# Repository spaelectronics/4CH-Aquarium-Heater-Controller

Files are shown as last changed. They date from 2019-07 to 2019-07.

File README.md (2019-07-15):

# Parts Needed
QTY: 1 - ITEM: C8 Power Socket Panel Mount  
URL: https://www.digikey.com/product-detail/en/qualtek/770W-X2-13/Q840-ND/1466563

QTY: 1 - ITEM: 4.7K Ohm Resistor  
URL: https://www.taydaelectronics.com/10-x-resistor-4-7k-ohm-1-4w-1-metal-film-pkg-of-10.html

QTY: 1 - ITEM: 3300UF 16V ELECTROLYTIC CAPACITOR  
URL: https://www.taydaelectronics.com/capacitors/electrolytic-capacitors/3300uf-16v-105c-radial-electrolytic-capacitor-13x21mm.html

QTY: 4 - ITEM: 3.5mm Stereo Plug  
URL: https://www.taydaelectronics.com/3-5mm-stereo-plug.html

QTY: 4 - ITEM: 3.5mm Stereo Jack  
URL: https://www.taydaelectronics.com/pj-392-3-5mm-stereo-enclosed-chassis-socket.html

QTY: 4 - ITEM: DS18B20 Waterproof Temperature Sensor  
URL: https://www.banggood.com/DS18B20-Waterproof-Digital-Temperature-Temp-Sensor-Probe-1M-2M-3M-5M-10M-15M-p-983801.html

QTY: 4 - ITEM: 2 Prong US Power Socket  
URL: https://www.amazon.com/uxcell-Panel-Mount-Outlet-Socket/dp/B01GKMPXTO/

QTY: 1 - ITEM: Passive Piezo Buzzer  
URL: https://www.banggood.com/DC-1-30V-2-Pins-Passive-Electronic-Piezoelectric-Piezo-Buzzer-p-978657.html

QTY: 1 - ITEM: AC-DC 5V 1A Step Down Module  
URL: https://www.banggood.com/5V-1A-AC-DC-Power-Supply-Step-Down-Module-Bare-Board-p-980522.html

QTY: 1 - ITEM: LCD Keypad Arduino Shield  
URL: https://www.banggood.com/Keypad-Shield-Blue-Backlight-For-Arduino-Robot-LCD-1602-Board-p-79326.html

QTY: 1 - ITEM: Arduino UNO  
URL: https://www.banggood.com/RobotDyn-UNO-R3-ATmega328P-A6-A7-Pin-MicroUSB-Module-For-Arduino-DIY-p-1129191.html

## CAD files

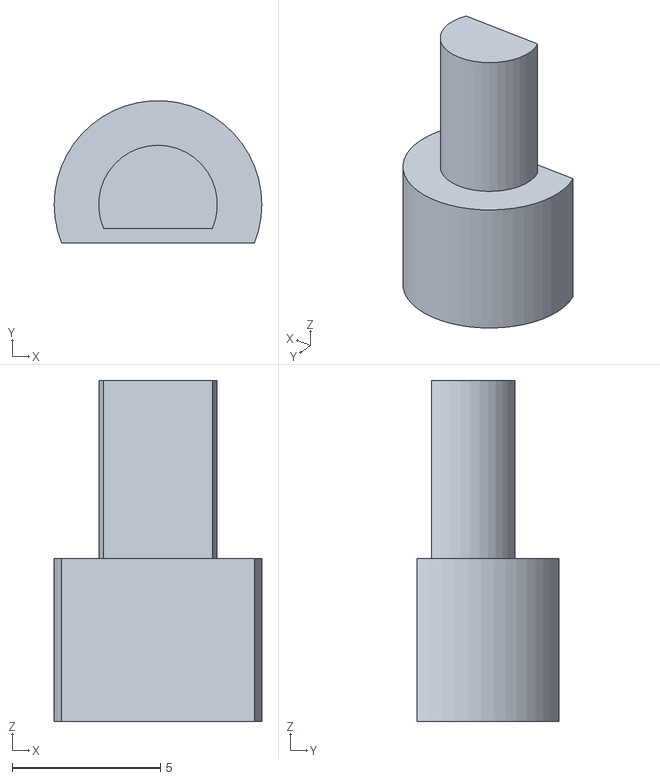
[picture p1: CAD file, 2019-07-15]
STL Files/buttonRstV3.STL
7.00 x 4.79 x 11.5

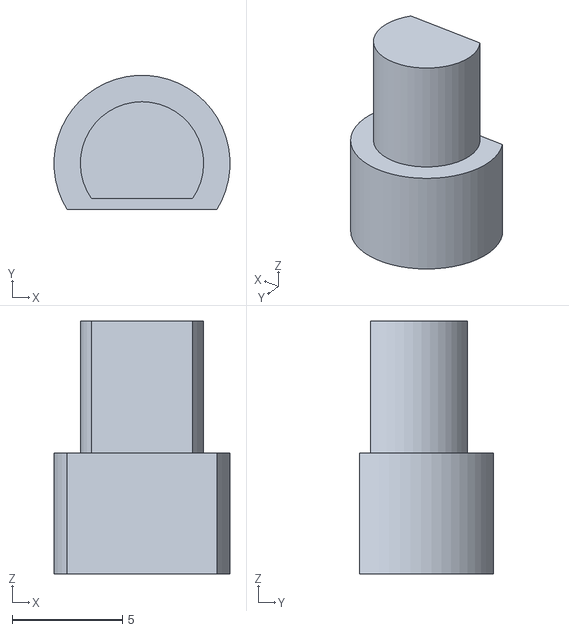
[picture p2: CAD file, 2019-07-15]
STL Files/buttonDirV3.STL
7.99 x 6.09 x 11.5

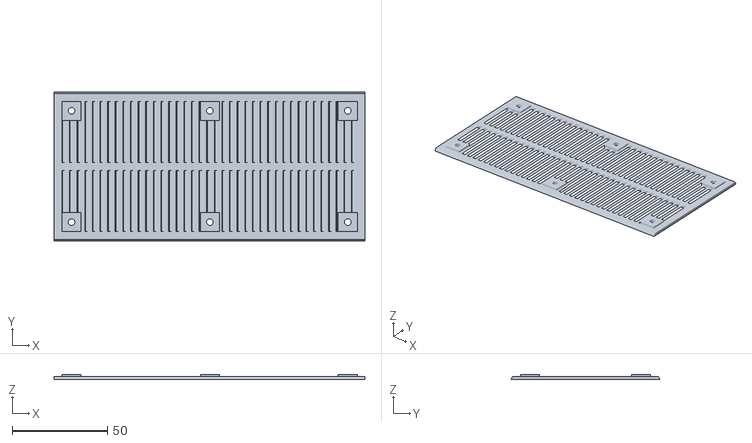
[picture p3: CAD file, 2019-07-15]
STL Files/Cover.stl
163.2 x 78.2 x 2.75

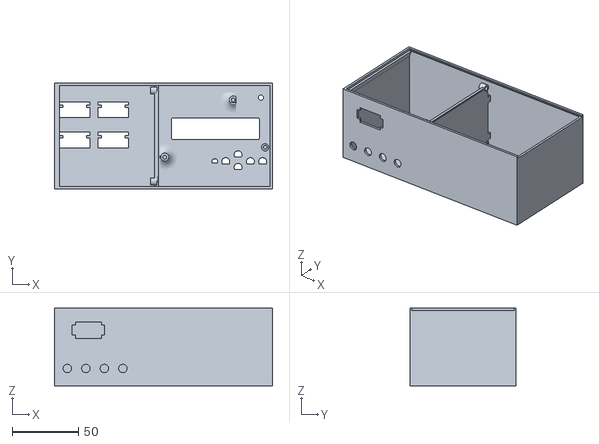
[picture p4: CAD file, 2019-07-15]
STL Files/Case.stl
165.0 x 80.0 x 59.0

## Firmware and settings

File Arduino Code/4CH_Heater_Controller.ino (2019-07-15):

#include <avr/wdt.h>
#include <EEPROM.h>
#include <EEWrap.h>
#include <OneWire.h>
#include <DallasTemperature.h>
#include <ErriezLCDKeypadShield.h>
#include <elapsedMillis.h>

// Define Pins
#define PIN_BUZZ 3
#define ONE_WIRE_BUS 2
#define RELAY1 A2
#define RELAY2 A1
#define RELAY3 A4
#define RELAY4 A3

#define TEMPERATURE_PRECISION 12

// Initilize Libraries
OneWire oneWire(ONE_WIRE_BUS);       // Setup a oneWire instance to communicate with any OneWire device
DallasTemperature sensors(&oneWire); // Pass oneWire reference to DallasTemperature library
elapsedMillis timeElapsed;           //declare global if you don't want it reset every time loop runs
elapsedMillis timeoutElapsed;           //declare global if you don't want it reset every time loop runs
LCDKeypadShield shield;

unsigned int interval = 1000;   // delay in milliseconds between reading the sensors.
unsigned int timeout = 10000;   // delay in milliseconds between reading the sensors.
int deviceCount = 0;
byte lastKey = 0;
byte currentKey = 0;
int selectRow = 0;
int selectMenu = 0;
byte displayMode = 0;
bool flash;

// Local Variables to store the current temperature
float tempCH1;
float tempCH2;
float tempCH3;
float tempCH4;

// Local Variables for Sensor Addresses (To save on EEPROM wear)
DeviceAddress sensorA;
DeviceAddress sensorB;
DeviceAddress sensorC;
DeviceAddress sensorD;

// EEPROM (EEWrap) Variables for Sensor Addresses
uint8_e addr1[8] EEMEM;
uint8_e addr2[8] EEMEM;
uint8_e addr3[8] EEMEM;
uint8_e addr4[8] EEMEM;

// EEPROM (EEWrap) Variables for Set Temperatures
float_e setTempCH1 EEMEM;
float_e setTempCH2 EEMEM;
float_e setTempCH3 EEMEM;
float_e setTempCH4 EEMEM;

// EEPROM (EEWrap) Variables for Settings
bool_e firstRun EEMEM;
bool_e isCelsius EEMEM;
float_e differential EEMEM;
uint8_e firstRunStep EEMEM;
uint8_e highAlarm EEMEM;
uint8_e lowAlarm EEMEM;

void setup(void)
{
  // Enable Watchdog Timer
  watchdogSetup();
  
  pinMode(RELAY1, OUTPUT);
  pinMode(RELAY2, OUTPUT);
  pinMode(RELAY3, OUTPUT);
  pinMode(RELAY4, OUTPUT);
  digitalWrite(RELAY1, HIGH);
  digitalWrite(RELAY2, HIGH);
  digitalWrite(RELAY3, HIGH);
  digitalWrite(RELAY4, HIGH);

  sensors.begin();  // Start up the library
  sensors.setResolution(TEMPERATURE_PRECISION);
  shield.backlightOn();

  if (analogRead(0) < 800) {
    shield.setCursor(0, 0);  // First character first line
    shield.print(F("Resetting..."));
    firstRun = false;
    isCelsius = false;
    differential = 0.5;
    firstRunStep = 0;
    highAlarm = 82;
    lowAlarm = 74;

    setTempCH1 = 78.0;
    setTempCH2 = 78.0;
    setTempCH3 = 78.0;
    setTempCH4 = 78.0;

    delay(1000);
    shield.setCursor(0, 1);  // First character second line
    shield.print(F("Reset Complete!"));
    delay(3000);
    shield.clear();
  }
  if (firstRunStep == 0) {
    shield.setCursor(0, 0);  // First character first line
    shield.print(F("Locating sensors"));
    shield.setCursor(0, 1);  // First character second line
    shield.print(F("Found: "));
    shield.setCursor(6, 1);
    deviceCount = sensors.getDeviceCount();
    shield.print(deviceCount, DEC);

    tone(PIN_BUZZ, 2000, 1000);
    delay(3000);
    shield.clear();
  }

  // Pull all the Sensor Addresses from EEPROM (EEWrap)
  for ( int i = 0 ; i < 8 ; ++i ) {
    sensorA[ i ] = addr1[ i ];
  }
  for ( int i = 0 ; i < 8 ; ++i ) {
    sensorB[ i ] = addr2[ i ];
  }
  for ( int i = 0 ; i < 8 ; ++i ) {
    sensorC[ i ] = addr3[ i ];
  }
  for ( int i = 0 ; i < 8 ; ++i ) {
    sensorD[ i ] = addr4[ i ];
  }

  if (!firstRun) {
    FirstRun();
  }
  sensors.setWaitForConversion(false);
}

void loop() {
  wdt_reset();                  // Resets the Watchdog Timer.
  if (timeElapsed > interval)
  {
    if (displayMode == 0) {
      getTemp();
      processAlarms();
      processRelays();              // Process the relays (temperature controlled).
    }
    updateDisplay();              // Updates the display for the menu system.
    timeElapsed = 0;              // reset the counter to 0 so the counting starts over...
  }

  if (timeoutElapsed > timeout)
  {
    if (displayMode > 0) {
      displayMode = 0;
      selectMenu = 0;
    }
    interval = 1000;
    timeoutElapsed = 0;              // reset the counter to 0 so the counting starts over...
  }

  // Read buttons
  currentKey = shield.getButtons();
  if (currentKey != lastKey) {
    switch (currentKey) {
      case ButtonRight:
        tone(PIN_BUZZ, 3000, 50);
        if (displayMode == 0 || displayMode == 1) {
          selectRow++;
          if (selectRow > 3)  selectRow = 0;
          interval = 500;
          displayMode = 1;
          timeoutElapsed = 0;
          flash = true;
          updateDisplay();
        } else if (displayMode == 2) {
          interval = 500;
          flash = false;
          timeElapsed = 0;
          timeoutElapsed = 0;
          buttonPress(ButtonRight);
          updateDisplay();
        }
        break;
      case ButtonLeft:
        tone(PIN_BUZZ, 3000, 50);
        if (displayMode == 0 || displayMode == 1) {
          selectRow--;
          if (selectRow < 0)  selectRow = 3;
          interval = 500;
          displayMode = 1;
          timeoutElapsed = 0;
          flash = true;
          updateDisplay();
        } else if (displayMode == 2) {
          interval = 500;
          flash = false;
          timeElapsed = 0;
          timeoutElapsed = 0;
          buttonPress(ButtonLeft);
          updateDisplay();
        }
        break;
      case ButtonUp:
        tone(PIN_BUZZ, 3000, 50);
        if (displayMode == 0 || displayMode == 1) {
          tempUp();
          interval = 500;
          flash = false;
          timeElapsed = 0;
          updateDisplay();
        } else if (displayMode == 2) {
          interval = 500;
          flash = false;
          timeElapsed = 0;
          timeoutElapsed = 0;
          buttonPress(ButtonUp);
          updateDisplay();
        }
        break;
      case ButtonDown:
        tone(PIN_BUZZ, 3000, 50);
        if (displayMode == 0 || displayMode == 1) {
          tempDown();
          interval = 500;
          flash = false;
          timeElapsed = 0;
          updateDisplay();
        } else if (displayMode == 2) {
          interval = 500;
          flash = false;
          timeElapsed = 0;
          timeoutElapsed = 0;
          buttonPress(ButtonDown);
          updateDisplay();
        }
        break;
      case ButtonSelect:
        tone(PIN_BUZZ, 3000, 50);
        if (displayMode == 0) {
          displayMode = 2;
          interval = 500;
          flash = false;
          timeElapsed = 0;
          timeoutElapsed = 0;
          updateDisplay();
        } else if (displayMode == 1) {
          displayMode = 0;
          selectMenu = 0;
          interval = 1000;
        } else if (displayMode == 2) {
          interval = 500;
          flash = false;
          timeElapsed = 0;
          timeoutElapsed = 0;
          buttonPress(ButtonSelect);
          updateDisplay();
        }
        break;
      case ButtonNone:
        break;
      default:
        break;
    }
    lastKey = currentKey;
  }
}



void watchdogSetup(void) {
  cli();
  wdt_reset();
  /*
    WDTCSR configuration:
    WDIE = 1: Interrupt Enable
    WDE = 1 :Reset Enable
    See table for time-out variations:
    WDP3 = 0 :For 1000ms Time-out
    WDP2 = 1 :For 1000ms Time-out
    WDP1 = 1 :For 1000ms Time-out
    WDP0 = 0 :For 1000ms Time-out
  */
  // Enter Watchdog Configuration mode:
  WDTCSR |= (1 << WDCE) | (1 << WDE);
  // Set Watchdog settings:
  WDTCSR = (0 << WDIE) | (1 << WDE) |
           (1 << WDP3) | (0 << WDP2) | (0 << WDP1) |
           (1 << WDP0);

  sei();
}



void buttonPress(int x) {
  if (x == ButtonUp) {
    selectMenu--;
    if (selectMenu < 0) selectMenu = 0;
  }

  if (x == ButtonDown) {
    selectMenu++;
    if (selectMenu > 7) selectMenu = 7;
  }

  if (x == ButtonRight) {
    if (selectMenu == 0) {
      isCelsius = !isCelsius;
      convertSetTemps();
    } else if (selectMenu == 1) {
      differential += 0.1;
      if (differential > 4.0) differential = 4.0;
    } else if (selectMenu == 2) {
      lowAlarm++;
      if (isCelsius) {
        if (lowAlarm > 26) lowAlarm = 26;
      } else {
        if (lowAlarm > 80) lowAlarm = 80;
      }
    } else if (selectMenu == 3) {
      highAlarm++;
      if (isCelsius) {
        if (highAlarm > 33) highAlarm = 33;
      } else {
        if (highAlarm > 90) highAlarm = 90;
      }
    }
  }

  if (x == ButtonLeft) {
    if (selectMenu == 0) {
      isCelsius = !isCelsius;
      convertSetTemps();
    } else if (selectMenu == 1) {
      differential -= 0.1;
      if (differential < 0.2) differential = 0.2;
    } else if (selectMenu == 2) {
      lowAlarm--;
      if (isCelsius) {
        if (lowAlarm < 12) lowAlarm = 12;
      } else {
        if (lowAlarm < 55) lowAlarm = 55;
      }
    } else if (selectMenu == 3) {
      highAlarm--;
      if (isCelsius) {
        if (highAlarm < 18) highAlarm = 18;
      } else {
        if (highAlarm < 65) highAlarm = 65;
      }
    }
  }

  if (x == ButtonSelect) {
    if (selectMenu == 0) {
      isCelsius = !isCelsius;
      convertSetTemps();
    } else if (selectMenu == 4) {
      hardReset();
    } else if (selectMenu == 5) {
      testRelays();
    } else if (selectMenu == 6) {
      firstRun = false;
      firstRunStep = 0;
      UnplugSensors();
      FirstRun();
    } else if (selectMenu == 7) {
      displayMode = 0;
      selectMenu = 0;
      interval = 1000;
    }
  }
}


void updateDisplay() {
  if (displayMode == 1) {
    if (selectRow == 0) {
      shield.clear();
      if (!flash) {
        shield.setCursor(0, 0);
        shield.print(setTempCH1);
        flash = true;
      } else {
        flash = false;
      }
      shield.setCursor(8, 0);
      shield.print(setTempCH2);
      shield.setCursor(0, 1);
      shield.print(setTempCH3);
      shield.setCursor(8, 1);
      shield.print(setTempCH4);
    }

    if (selectRow == 1) {
      shield.clear();
      shield.setCursor(0, 0);
      shield.print(setTempCH1);
      if (!flash) {
        shield.setCursor(8, 0);
        shield.print(setTempCH2);
        flash = true;
      } else {
        flash = false;
      }
      shield.setCursor(0, 1);
      shield.print(setTempCH3);
      shield.setCursor(8, 1);
      shield.print(setTempCH4);
    }

    if (selectRow == 2) {
      shield.clear();
      shield.setCursor(0, 0);
      shield.print(setTempCH1);
      shield.setCursor(8, 0);
      shield.print(setTempCH2);
      if (!flash) {
        shield.setCursor(0, 1);
        shield.print(setTempCH3);
        flash = true;
      } else {
        flash = false;
      }
      shield.setCursor(8, 1);
      shield.print(setTempCH4);
    }

    if (selectRow == 3) {
      shield.clear();
      shield.setCursor(0, 0);
      shield.print(setTempCH1);
      shield.setCursor(8, 0);
      shield.print(setTempCH2);
      shield.setCursor(0, 1);
      shield.print(setTempCH3);
      if (!flash) {
        shield.setCursor(8, 1);
        shield.print(setTempCH4);
        flash = true;
      } else {
        flash = false;
      }
    }



  } else if (displayMode == 2) {
    if (selectMenu == 0) {
      shield.clear();
      shield.setCursor(0, 0);
      if (!flash) {
        if (isCelsius) shield.print(F("Unit: Celsius"));
        else shield.print(F("Unit: Fahrenheit"));
        flash = true;
      } else {
        flash = false;
      }
      shield.setCursor(0, 1);
      shield.print(F("Temp Swing:"));
      shield.setCursor(12, 1);
      shield.print(differential);
    }

    if (selectMenu == 1) {
      shield.clear();
      shield.setCursor(0, 0);
      if (isCelsius) shield.print(F("Unit: Celsius"));
      else shield.print(F("Unit: Fahrenheit"));
      shield.setCursor(0, 1);
      if (!flash) {
        shield.print(F("Temp Swing:"));
        shield.setCursor(12, 1);
        shield.print(differential);
        flash = true;
      } else {
        flash = false;
      }
    }

    if (selectMenu == 2) {
      shield.clear();
      shield.setCursor(0, 0);
      if (!flash) {
        shield.print(F("Low Alarm:"));
        shield.setCursor(11, 0);
        shield.print(lowAlarm);
        flash = true;
      } else {
        flash = false;
      }
      shield.setCursor(0, 1);
      shield.print(F("High Alarm:"));
      shield.setCursor(12, 1);
      shield.print(highAlarm);
    }

    if (selectMenu == 3) {
      shield.clear();
      shield.setCursor(0, 0);
      shield.print(F("Low Alarm:"));
      shield.setCursor(11, 0);
      shield.print(lowAlarm);
      shield.setCursor(0, 1);
      if (!flash) {
        shield.print(F("High Alarm:"));
        shield.setCursor(12, 1);
        shield.print(highAlarm);
        flash = true;
      } else {
        flash = false;
      }
    }

    if (selectMenu == 4) {
      shield.clear();
      shield.setCursor(0, 0);
      if (!flash) {
        shield.print(F("Hard Reset"));
        flash = true;
      } else {
        flash = false;
      }
      shield.setCursor(0, 1);
      shield.print(F("Test Outlets"));
    }

    if (selectMenu == 5) {
      shield.clear();
      shield.setCursor(0, 0);
      shield.print(F("Hard Reset"));
      shield.setCursor(0, 1);
      if (!flash) {
        shield.print(F("Test Outlets"));
        flash = true;
      } else {
        flash = false;
      }
    }

    if (selectMenu == 6) {
      shield.clear();
      shield.setCursor(0, 0);
      if (!flash) {
        shield.print(F("Setup Sensors"));
        flash = true;
      } else {
        flash = false;
      }
      shield.setCursor(0, 1);
      shield.print(F("Exit Menu"));
    }

    if (selectMenu == 7) {
      shield.clear();
      shield.setCursor(0, 0);
      shield.print(F("Setup Sensors"));
      shield.setCursor(0, 1);
      if (!flash) {
        shield.print(F("Exit Menu"));
        flash = true;
      } else {
        flash = false;
      }
    }
  }
}


void tempUp() {
  if (selectRow == 0) {
    if (displayMode == 1) {
      timeoutElapsed = 0;
      setTempCH1 += 0.1;
      if (isCelsius) {
        if (setTempCH1 > 33) setTempCH1 = 33;
      } else {
        if (setTempCH1 > 92) setTempCH1 = 92;
      }
    } else {
      displayMode = 1;
    }
  }

  if (selectRow == 1) {
    if (displayMode == 1) {
      timeoutElapsed = 0;
      setTempCH2 += 0.1;
      if (isCelsius) {
        if (setTempCH2 > 33) setTempCH2 = 33;
      } else {
        if (setTempCH2 > 92) setTempCH2 = 92;
      }
    } else {
      displayMode = 1;
    }
  }

  if (selectRow == 2) {
    if (displayMode == 1) {
      timeoutElapsed = 0;
      setTempCH3 += 0.1;
      if (isCelsius) {
        if (setTempCH3 > 33) setTempCH3 = 33;
      } else {
        if (setTempCH3 > 92) setTempCH3 = 92;
      }
    } else {
      displayMode = 1;
    }
  }

  if (selectRow == 3) {
    if (displayMode == 1) {
      timeoutElapsed = 0;
      setTempCH4 += 0.1;
      if (isCelsius) {
        if (setTempCH4 > 33) setTempCH4 = 33;
      } else {
        if (setTempCH4 > 92) setTempCH4 = 92;
      }
    } else {
      displayMode = 1;
    }
  }
}


void tempDown() {
  if (selectRow == 0) {
    if (displayMode == 1) {
      timeoutElapsed = 0;
      setTempCH1 -= 0.1;
      if (isCelsius) {
        if (setTempCH1 < 15) setTempCH1 = 15;
      } else {
        if (setTempCH1 < 60) setTempCH1 = 60;
      }
    } else {
      displayMode = 1;
    }
  }

  if (selectRow == 1) {
    if (displayMode == 1) {
      timeoutElapsed = 0;
      setTempCH2 -= 0.1;
      if (isCelsius) {
        if (setTempCH2 < 15) setTempCH2 = 15;
      } else {
        if (setTempCH2 < 60) setTempCH2 = 60;
      }
    } else {
      displayMode = 1;
    }
  }

  if (selectRow == 2) {
    if (displayMode == 1) {
      timeoutElapsed = 0;
      setTempCH3 -= 0.1;
      if (isCelsius) {
        if (setTempCH3 < 15) setTempCH3 = 15;
      } else {
        if (setTempCH3 < 60) setTempCH3 = 60;
      }
    } else {
      displayMode = 1;
    }
  }

  if (selectRow == 3) {
    if (displayMode == 1) {
      timeoutElapsed = 0;
      setTempCH4 -= 0.1;
      if (isCelsius) {
        if (setTempCH4 < 15) setTempCH4 = 15;
      } else {
        if (setTempCH4 < 60) setTempCH4 = 60;
      }
    } else {
      displayMode = 1;
    }
  }
}



void getTemp() {
  sensors.requestTemperatures();
  shield.clear();

  if (sensorA[0] != 0) {
    if (isCelsius) tempCH1 = sensors.getTempC(sensorA);
    else tempCH1 = sensors.getTempF(sensorA);
    shield.setCursor(0, 0);

    if (tempCH1 == DEVICE_DISCONNECTED_C || tempCH1 == DEVICE_DISCONNECTED_F) {
      shield.print(F("???"));
    } else if (tempCH1 == 185) {
      shield.print(F("INIT"));
    } else {
      shield.print(tempCH1);
    }

  } else {
    shield.setCursor(0, 0);
    shield.print(F("---"));
  }


  if (sensorB[0] != 0) {
    if (isCelsius) tempCH2 = sensors.getTempC(sensorB);
    else tempCH2 = sensors.getTempF(sensorB);
    shield.setCursor(8, 0);

    if (tempCH2 == DEVICE_DISCONNECTED_C || tempCH2 == DEVICE_DISCONNECTED_F) {
      shield.print(F("???"));
    } else if (tempCH2 == 185) {
      shield.print(F("INIT"));
    } else {
      shield.print(tempCH2);
    }

  } else {
    shield.setCursor(8, 0);
    shield.print(F("---"));
  }


  if (sensorC[0] != 0) {
    if (isCelsius) tempCH3 = sensors.getTempC(sensorC);
    else tempCH3 = sensors.getTempF(sensorC);
    shield.setCursor(0, 1);

    if (tempCH3 == DEVICE_DISCONNECTED_C || tempCH3 == DEVICE_DISCONNECTED_F) {
      shield.print(F("???"));
    } else if (tempCH3 == 185) {
      shield.print(F("INIT"));
    } else {
      shield.print(tempCH3);
    }

  } else {
    shield.setCursor(0, 1);
    shield.print(F("---"));
  }


  if (sensorD[0] != 0) {
    if (isCelsius) tempCH4 = sensors.getTempC(sensorD);
    else tempCH4 = sensors.getTempF(sensorD);
    shield.setCursor(8, 1);

    if (tempCH4 == DEVICE_DISCONNECTED_C || tempCH4 == DEVICE_DISCONNECTED_F) {
      shield.print(F("???"));
    } else if (tempCH4 == 185) {
      shield.print(F("INIT"));
    } else {
      shield.print(tempCH4);
    }

  } else {
    shield.setCursor(8, 1);
    shield.print(F("---"));
  }
}



void UnplugSensors () {
  sensors.begin();
  deviceCount = sensors.getDeviceCount();
  if (deviceCount > 0) {
    shield.clear();
    shield.setCursor(0, 0);
    shield.print(F("Please unplug"));
    shield.setCursor(0, 1);
    shield.print(F("all temp sensors"));

    while (deviceCount > 0) {
      sensors.begin();
      deviceCount = sensors.getDeviceCount();
      wdt_reset();  // Resets the Watchdog Timer.
      delay(200);
    }
    delay(1000);
    shield.clear();
  }
}
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
